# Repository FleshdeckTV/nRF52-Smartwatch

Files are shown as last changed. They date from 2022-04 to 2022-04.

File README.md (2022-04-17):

# nRF52-Smartwatch
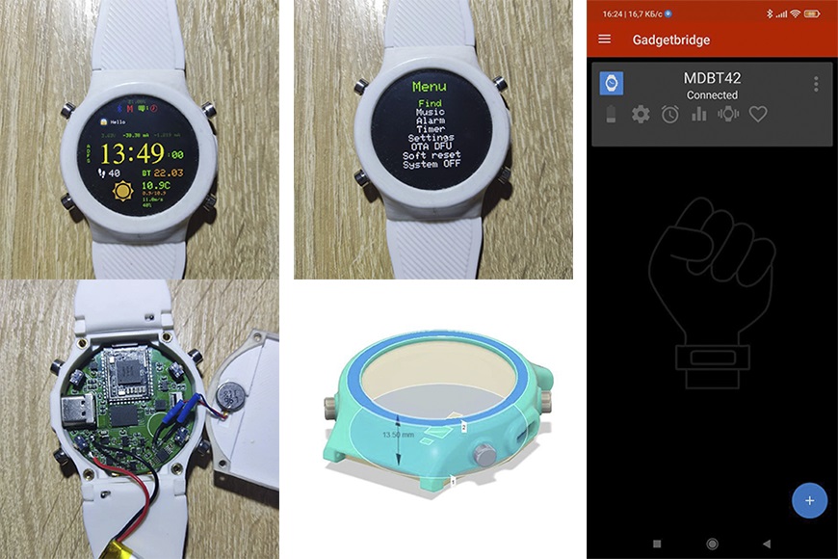
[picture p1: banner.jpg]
banner


Here you can find PCB files, software and some instructions.

Due to the current situation in Ukraine, I cannot continue working on the project at the moment, as soon as the war ends I will continue to work, you can support the project by donating to a crypto wallet or Patreon:

* BTC 1Fx1nvSsfxKMsXz7BsxxJzk7NQdWSS86Fd
* ETH 0xfeb67dc42bdb4252a39f2cb6f8ca42f192d4d32d

# Hardware

* nRF52840(Holyiot-18010)
* 240x240 IPS Display(GC9A01)
* BMA423 Accel(Steps and tilt wrist)
* 8Mb QSPI Flash Memory
* USB Type-C for programming and access to flash memory
* 4 Hardware Buttons
* MAX17055 1-Cell Fuel Gauge
* 500mAh LiPo battery
* DRV2605L Haptic Motor Controller 
* Small size

# Software

* Shows time
* Call notifications
* Message notifications
* Over 7-day battery life with BLE connected
* Gadgetbridge support
* BLE communication secured with passkey comparison pairing
* Current weather
* Music player control
* Flashlight mode
* Find phone function
* OTA update

# In Future
* Go to more available components
* Make other buttons for case(I bought buttons in a local store, but in Ukraine there is a war with Russia and the store will not work)
* Add NFC antena
* Add a pulse oximeter(MAXM86146)
* Draw more app and weather icons
* Using other displays

# You will need to install:
- [Arduino Core for Adafruit Bluefruit nRF52 Boards V1.0.0](https://github.com/adafruit/Adafruit_nRF52_Arduino)
- [Segger Embedded Studio Version 5.60a](https://www.segger.com/downloads/embedded-studio/)
It will also be required:
- J-Link or Black Magic Probe for programming bootloader

After installation Adafruit nRF52 Core V1.0.0 need to replace the files 
in the folder \AppData\Local\Arduino15\packages\adafruit\hardware\nrf52
And also add the necessary libraries
## The instructions will be updated

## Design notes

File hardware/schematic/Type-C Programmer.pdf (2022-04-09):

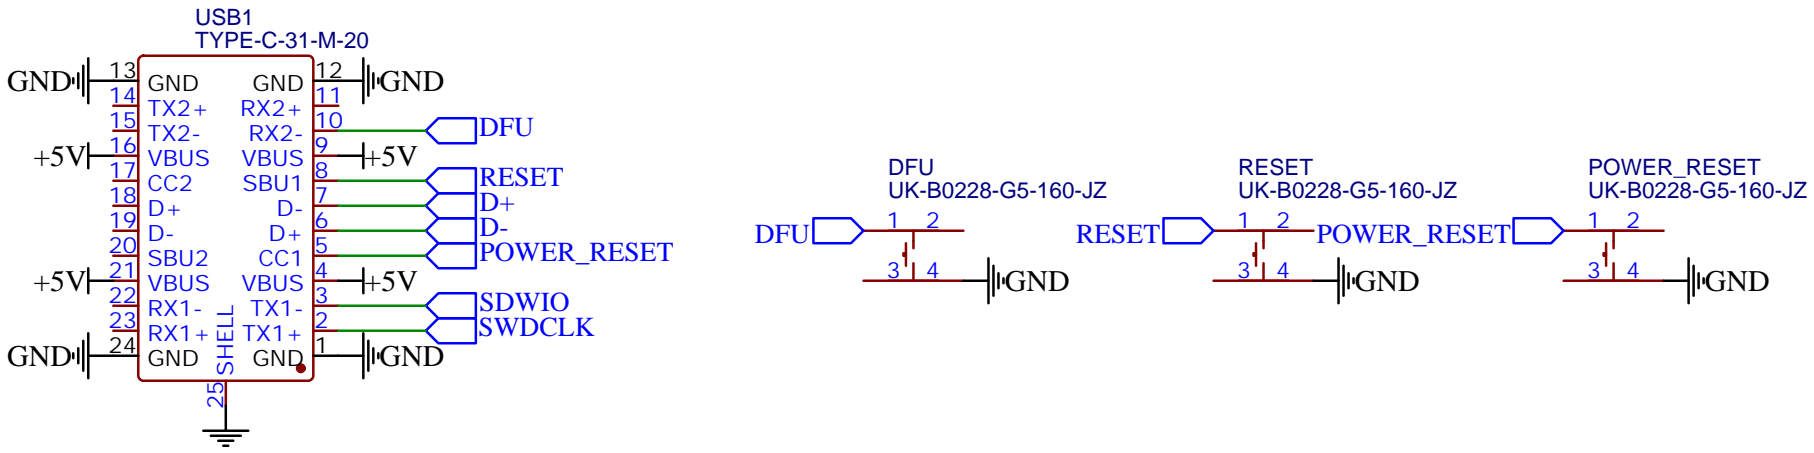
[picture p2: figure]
TYPE-C-31-M-20; USB1; GND 1; VBUS 4; SBU1 8; VBUS 9; RX2- 10 RX2+ 11 GND 12 GND 13 TX2+ 14 TX2- 15 VBUS 16 CC2 17 D+ 18 D- 19 SBU2 20 VBUS 21 RX1- 22 RX1+ 23 GND 24; SHELL 25; GND; DFU; RESET; POWER_RESET; 4 GND; POWER_RESET POWER_RESET; SWDCLK; SDWIO

### GND

U254-051N-4BH806

USB2

EP

6 EP

7 EP

8

EP

9

GND 5
ID 4
D+ 3
D- 2
VBUS 1

### GNDGND

### GNDGND

### GND

+5V

D+
D-

HDR-F-2.54_1x4

H1

1
2
3
4

+5V

### GND

SWDCLK
SDWIO

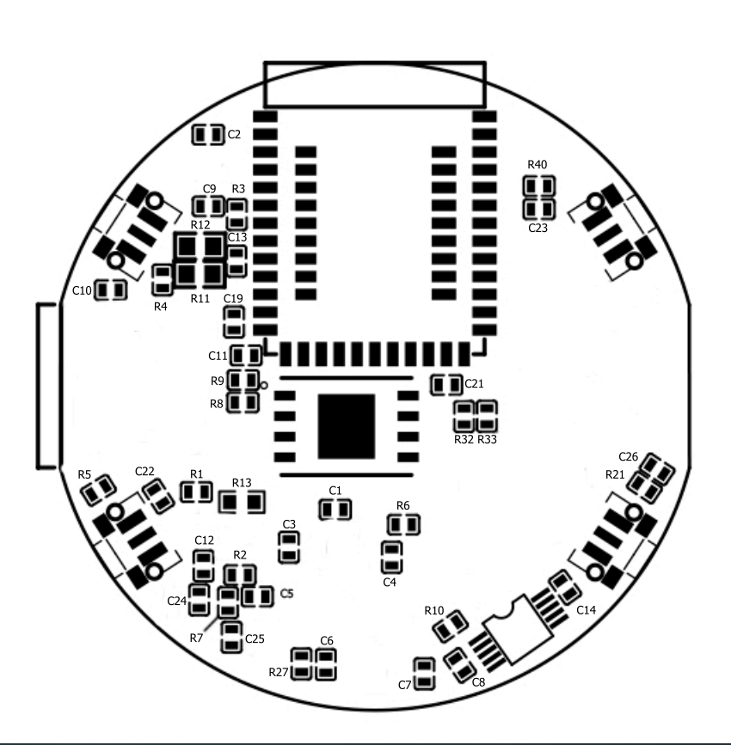
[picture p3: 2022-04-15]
hardware/schematic/Res&Cap_pos.PNG

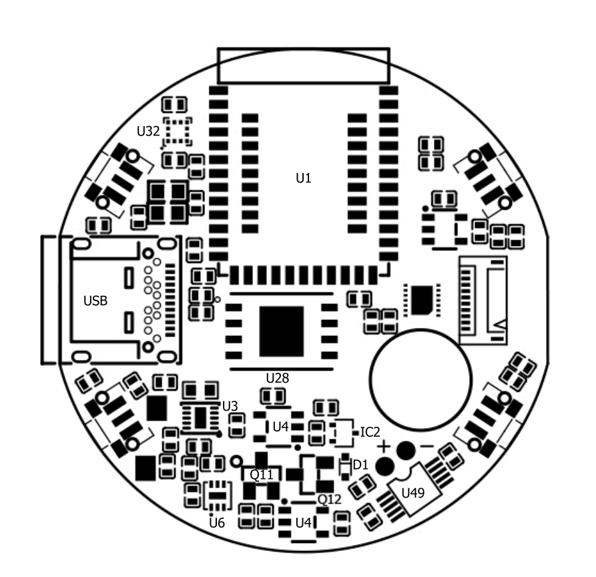
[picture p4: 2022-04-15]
hardware/schematic/IC_Pos.PNG

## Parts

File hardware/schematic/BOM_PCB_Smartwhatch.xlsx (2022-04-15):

Name | Designator | Quantity
0.1uF | C2,C9,C10,C19,C13,C23,C22,C24,C25,C26 | 10
0.47uF | C12 | 1
1uF | C1,C3,C4,C5,C6,C7,C8,C14 | 8
4.7uF | C11,C21 | 2
0.02 Ohm | R13 | 1 | https://lcsc.com/product-detail/Current-Sense-Resistors-Shunt-Resistors_Walter-Elec-STE0603MW50R020F_C156372.html
22 | R8,R9 | 2
100 | R27 | 1
4.7K | R32,R33 | 4
5k | R2 | 1
10k | R3,R4,R5,R6,R7,R10,R21,R40 | 8
100k | R1 | 1
820k | R11 | 1
2M | R12 | 1
SKRTLAE010 | SW1,SW2,SW3,SW4 | 4
USB31-TYPEC-32X41-XFS | USB | 1
Holyiot 18010 nRF52840 | U1 | 1
DRV2605LDGSR | U49 | 1
LTC4065LEDC | U6 | 1
TPS78233DDCT | U4 | 2
BMA423 | U32 | 1
MAX809TEXR | IC2 | 1
GD25Q64CYIGR | U28 | 1
MAX17055ETB+ | U3 | 1
1PS79SB30,135 | D1 | 1
IRLML6402 | Q12 | 1
2N7002 | Q11 | 1
GC9A01 |  | 1
Crystal Mineral Glass 38mm | https://www.aliexpress.com/item/4001120317134.html
Insert Nut M2x4 | https://www.aliexpress.com/item/4000585933306.html
Torx Screw M2x6 | https://www.aliexpress.com/item/33006942612.html
22mm Silicone Band | https://www.aliexpress.com/item/4000355024776.html
E8000 Clear Adhesive Sealant Glue | https://www.aliexpress.com/item/4000066263687.html
USB 3.1 Type-C SMT 24P Male | https://www.aliexpress.com/item/1005002157161417.html
602040 3.7V 500mAh Lipo | https://www.aliexpress.com/item/1005003629871046.html
Micro Motor | https://lcsc.com/product-detail/Micro-Motor-Motor_LNLON-C0820L-066678055-1601_C2685989.html

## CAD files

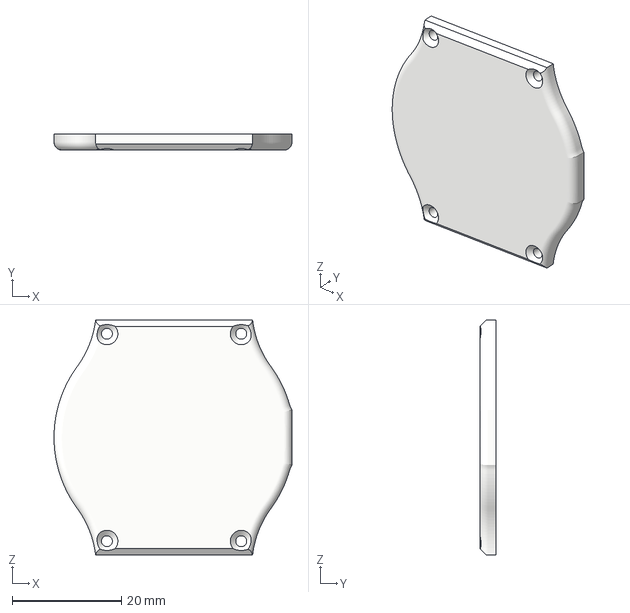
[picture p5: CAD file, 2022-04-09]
hardware/3d print watch case/watch cover.3mf
43.6 x 3.00 x 43.0 mm

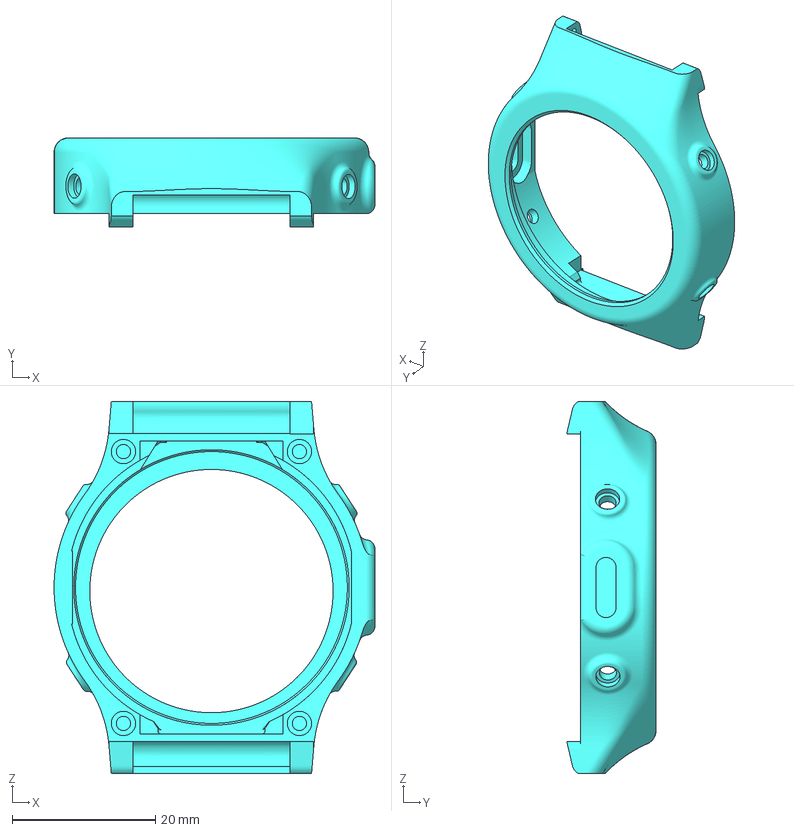
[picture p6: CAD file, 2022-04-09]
hardware/3d print watch case/watch case.3mf
44.8 x 12.5 x 52.0 mm

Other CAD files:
hardware/Fusion360-source/Smartwatch.f3d

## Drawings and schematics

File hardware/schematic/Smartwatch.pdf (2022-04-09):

This part is related to the pulse oximeter, currently not implemented, it is not necessary to install

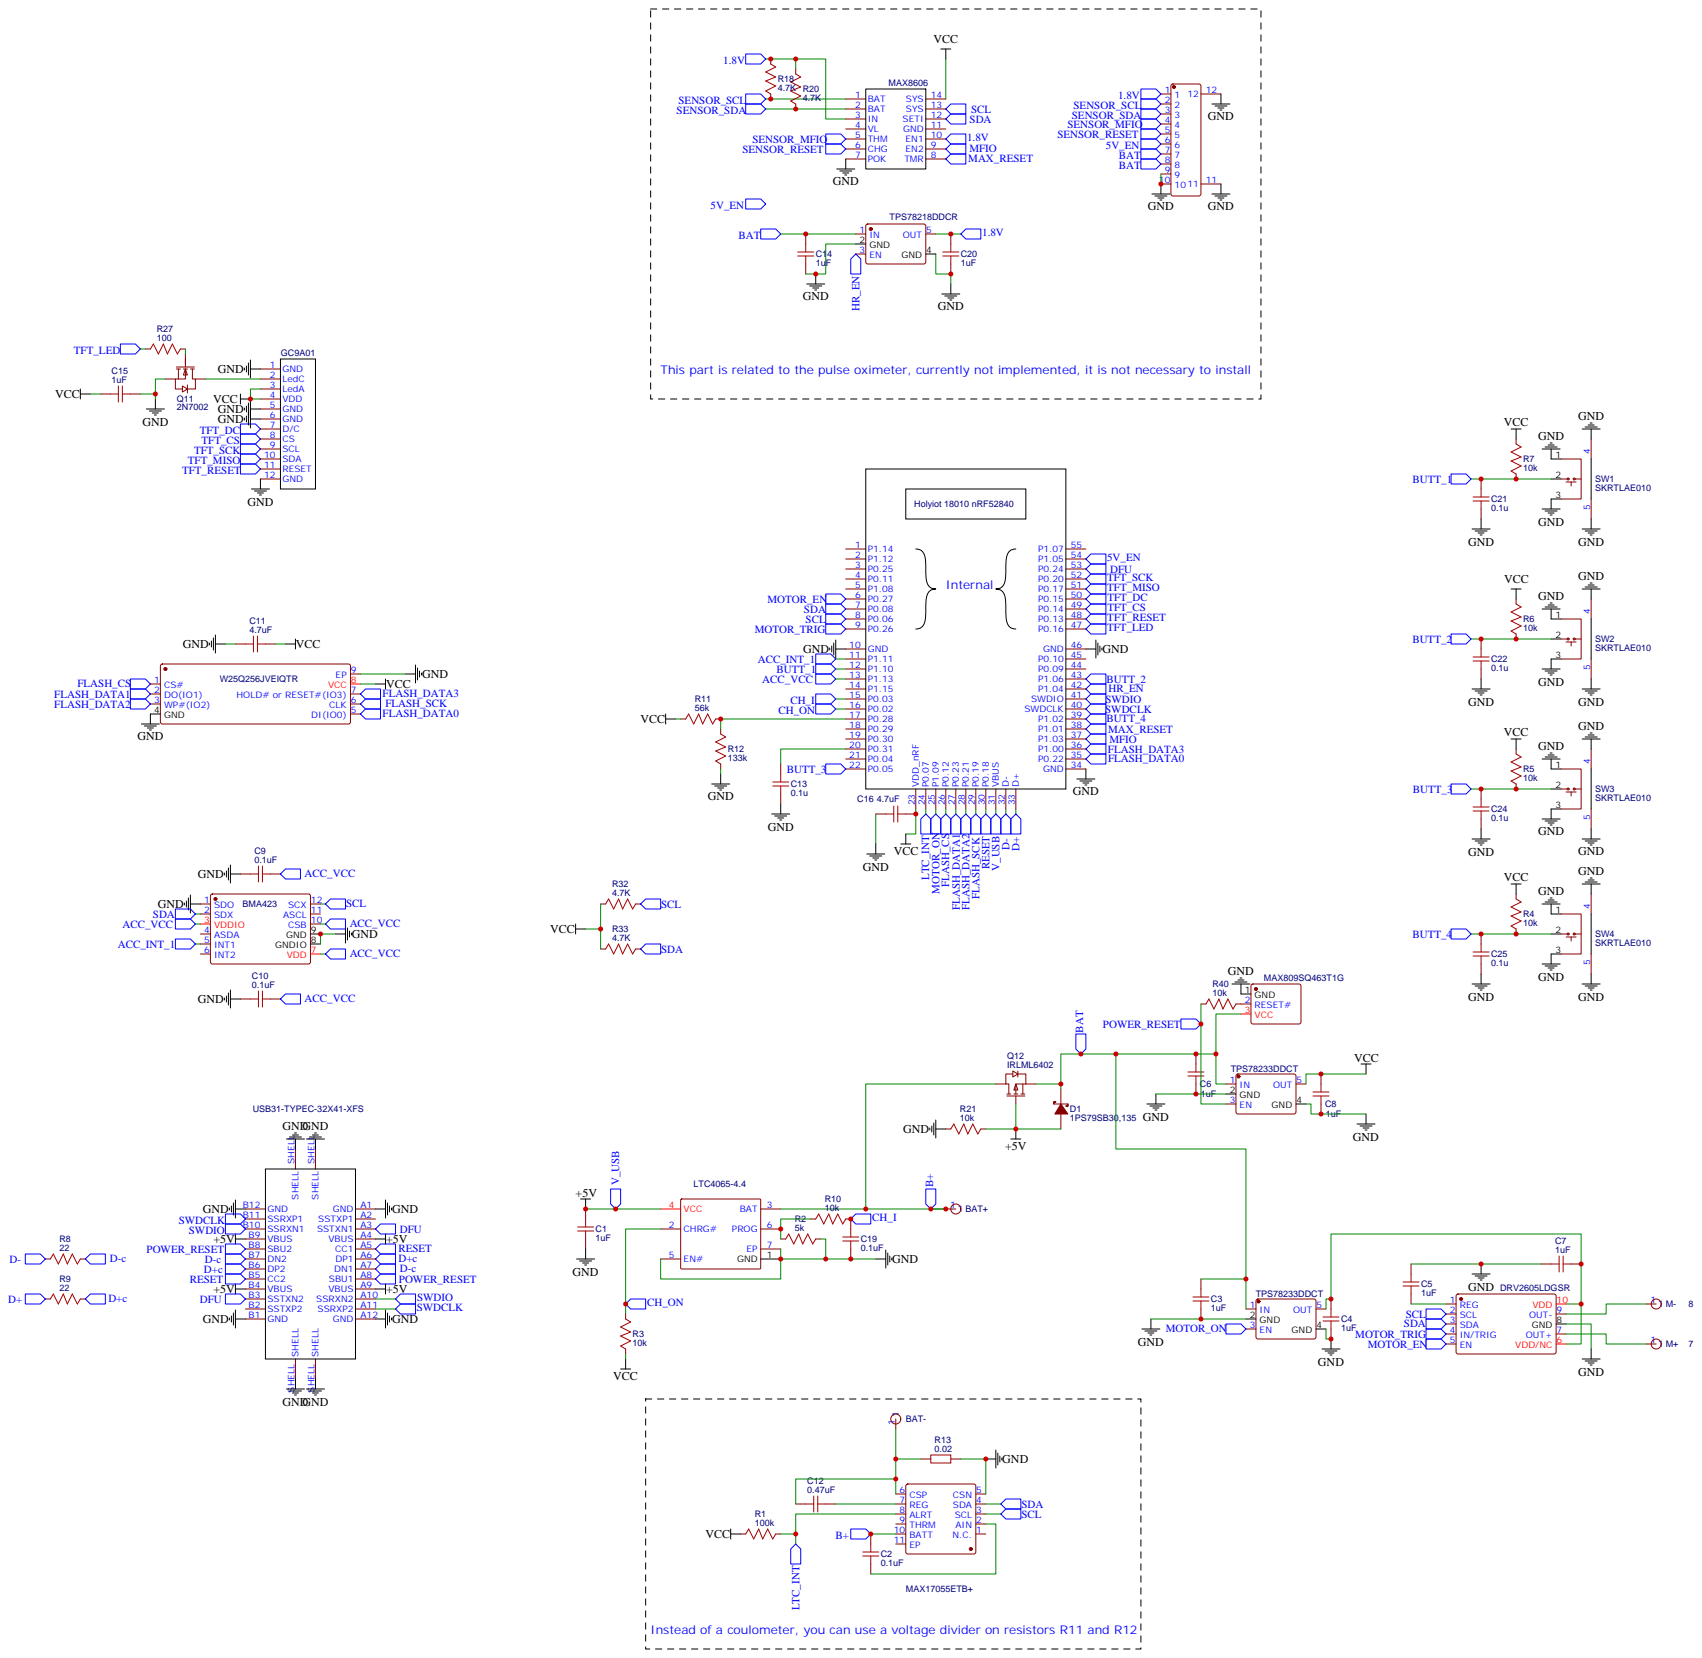
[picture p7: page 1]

MAX8606
EN1 10 GND 11 SETI 12 SYS 13 SYS 14

SHELL SHELL

Instead of a coulometer, you can use a voltage divider on resistors R11 and R12

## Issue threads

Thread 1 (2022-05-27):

Not an issue but just a general question!

TripleT-circuitmaker, 2022-05-27:
Hello!

I am working on my own little project for college which involves using the NRF52832 microcontroller and the GC9A01 LCD display, however, I cannot seem to get them to work with GIFs specifically.

I am currently programming this on the Arduino IDE using the Arduino_GFX library and I wanted to know if you can possibly share some insight on how to resolve this issue?

My main goal is just to display GIFs on the screen.
I am using the included ImageViewerAnimatedGIF example project (modified so it works with my board and LCD) however I can't display GIF's larger than 64 x 64. I'm trying to display 240 x 240 GIFs. The NRF I'm working with has 64 KB SRAM. How were you able to display so many things on your screen?

Please let me know if there is any advice or insight you can provide!

FleshdeckTV, 2022-05-29:
Hello, I'm using nrf52840, there is 256 kb of RAM, to draw pictures of 240x240 pixels you need more than 100 kb of RAM

Closed 2022-05-29.

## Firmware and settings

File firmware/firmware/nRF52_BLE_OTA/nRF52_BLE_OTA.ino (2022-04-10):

#include <bluefruit.h>

BLEDfu bledfu;

void setup() {

  Bluefruit.begin();
  Bluefruit.setTxPower(4);    
  bledfu.begin();
  startAdv();
  delay(100);
  enterOTADfu();
}

void startAdv(void){  
  Bluefruit.Advertising.addFlags(BLE_GAP_ADV_FLAGS_LE_ONLY_GENERAL_DISC_MODE);
  Bluefruit.Advertising.addTxPower();
  Bluefruit.Advertising.addName();
  Bluefruit.Advertising.restartOnDisconnect(true);
  Bluefruit.Advertising.setInterval(32, 244);    // in unit of 0.625 ms
  Bluefruit.Advertising.setFastTimeout(30);      // number of seconds in fast mode
  Bluefruit.Advertising.start(0);                // 0 = Don't stop advertising after n seconds  
}

void loop(){

}

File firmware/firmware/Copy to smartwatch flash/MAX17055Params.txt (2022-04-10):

CycleCount:1609;Rcomp0:26;TempCo:8766;Fullchcap:3192;Fullcapnom:3003;

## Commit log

2022-04-10 Firmware update
    Android apps:
    Gadjetbridge
    Weather
    nRF Tool
    [MAX17055Params.txt]
2022-04-15 Add BOM
    [BOM_PCB_Smartwhatch.xlsx]
